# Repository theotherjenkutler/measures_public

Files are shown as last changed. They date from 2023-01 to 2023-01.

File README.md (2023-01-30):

# Measures
## An ecosystem for detection of physiological indicators of empathy.
<p>MEASURES is a flexible web based, AI driven eco-system which lends itself to live performance, 
<br>installation in a gallery museum, festival or alone in one's bedroom while being simple enough 
<br>for anyone with WIFI and a smartphone to use.
<br>It fuses technology and emotion where technology is often sterile and intellectual and offers 
<br>tools for self reflection while creating a method of studying the phenomenon of empathy as a whole. 
<br>Ultimately, MEASURES offers a new way to feel connected and to experience one another across borders, 
<br>cultures, socioeconomic classes and other zones of isolation.

<p>Users wear an electronic wristband which provides audio cues and measures the participant's electrodermal
<br>activity. The data is transferred over WIFI to a server which processes the data and generates a unique sound work.
<br>Each sound work produced by a participant is subsequently analyzed for point of “excitation” using Opensmile 
<br>feature extraction trained by a custom piece specific data set. The results are used as the basis of the following 
<br>user's auditory stimuli and physiological data comparison to generate the next sound piece and so on. The sound 
<br>works are added to a public online archive. Participants can choose to disclose their identity or remain anonymous.
<br>To my knowledge, MEASURES is the first system in the artistic and scientific communities designed with the 
<br>specific purpose of quantifying and measuring empathy from auditory cues. MEASURES content originates from an 
<br>infinitely expansive pool of participant data is comprised of empathetic responses for an AI driven art work.

<p>The goals of this piece put the wealth seeking uses of AI such as advertising, facial/voice recognition, fraud 
<br>prevention and other commercial applications in the background. It focuses on AI as a tool to witness people in 
<br>the most human way possible – through experiencing a person feeling empathy.
<br>The form of MEASURES is also unique because the data collection device exists as an electronic art object and 
<br>generates an expansive bio-data driven archive of individual sound works, and is designed to be extremely 
<br>accessible as a tool for installation, real-time performance and solitary use.

<p>The hardware uses a custom EDA sensor based on the AD8608 op-amp and handmade carbon silicone sensor pads.
<br>MP3 decoding is handled by the VS1053b chip connected to the ESP32WROVER over SPI.
<br>For ADC it uses an ADS1115 IC over the I2C Bus. 
 
<p>This repo will include 
<br>- Arduino firmware code for the ESP32-WROVER,
<br>- Node-Red code with respective shell scripts, 
<br>- PureData patches for sonification, 
<br>- EAGLE CAD files of schematics and PCB layout,
<br>- TensorFlow and Pytorch code

<p>Server Requirements:
<br>- Ubuntu or similar
<br>- Icecast2 // icecast.org
<br>- FFMPEG // ffmpeg.org
<br>- PureData // puredata.info
<br>- Node-Red // nodered.org
<br>- inotifytools // https://github.com/inotify-tools/inotify-tools

<p>Device Firmware Requirements:
<br>- Arduino IDE + ESP32 Arduino
<br>- External Libraries:
<br>- Adafruit_VS1053 // https://github.com/adafruit/Adafruit_VS1053_Library
<br>- WiFi Manager // https://github.com/tzapu/WiFiManager
<br>- ADS1X15 // https://github.com/RobTillaart/ADS1X15

<p>Detailed system description:
<br>TODO

<p>Relavent links/Bibliography:
<br>TODO
<br>https://arxiv.org/pdf/2008.09743.pdf Guanghao Yin, Shouqian Sun, Dian Yu and Kejun Zhang*, Member, 
<br>IEEE in their paper A Efficient Multimodal Framework for Large Scale Emotion Recognition by Fusing Music 
<br>and Electrodermal Activity Signals. openSMILE https://audeering.github.io/opensmile/ to obtain external feature 
<br>vectors of audio cues

 <br>Measures is made possible in part by the New York State Council on the Arts with the support of the Office of 
 <br>the Governor and the New York State Legislature and Wave Farm.
<br>

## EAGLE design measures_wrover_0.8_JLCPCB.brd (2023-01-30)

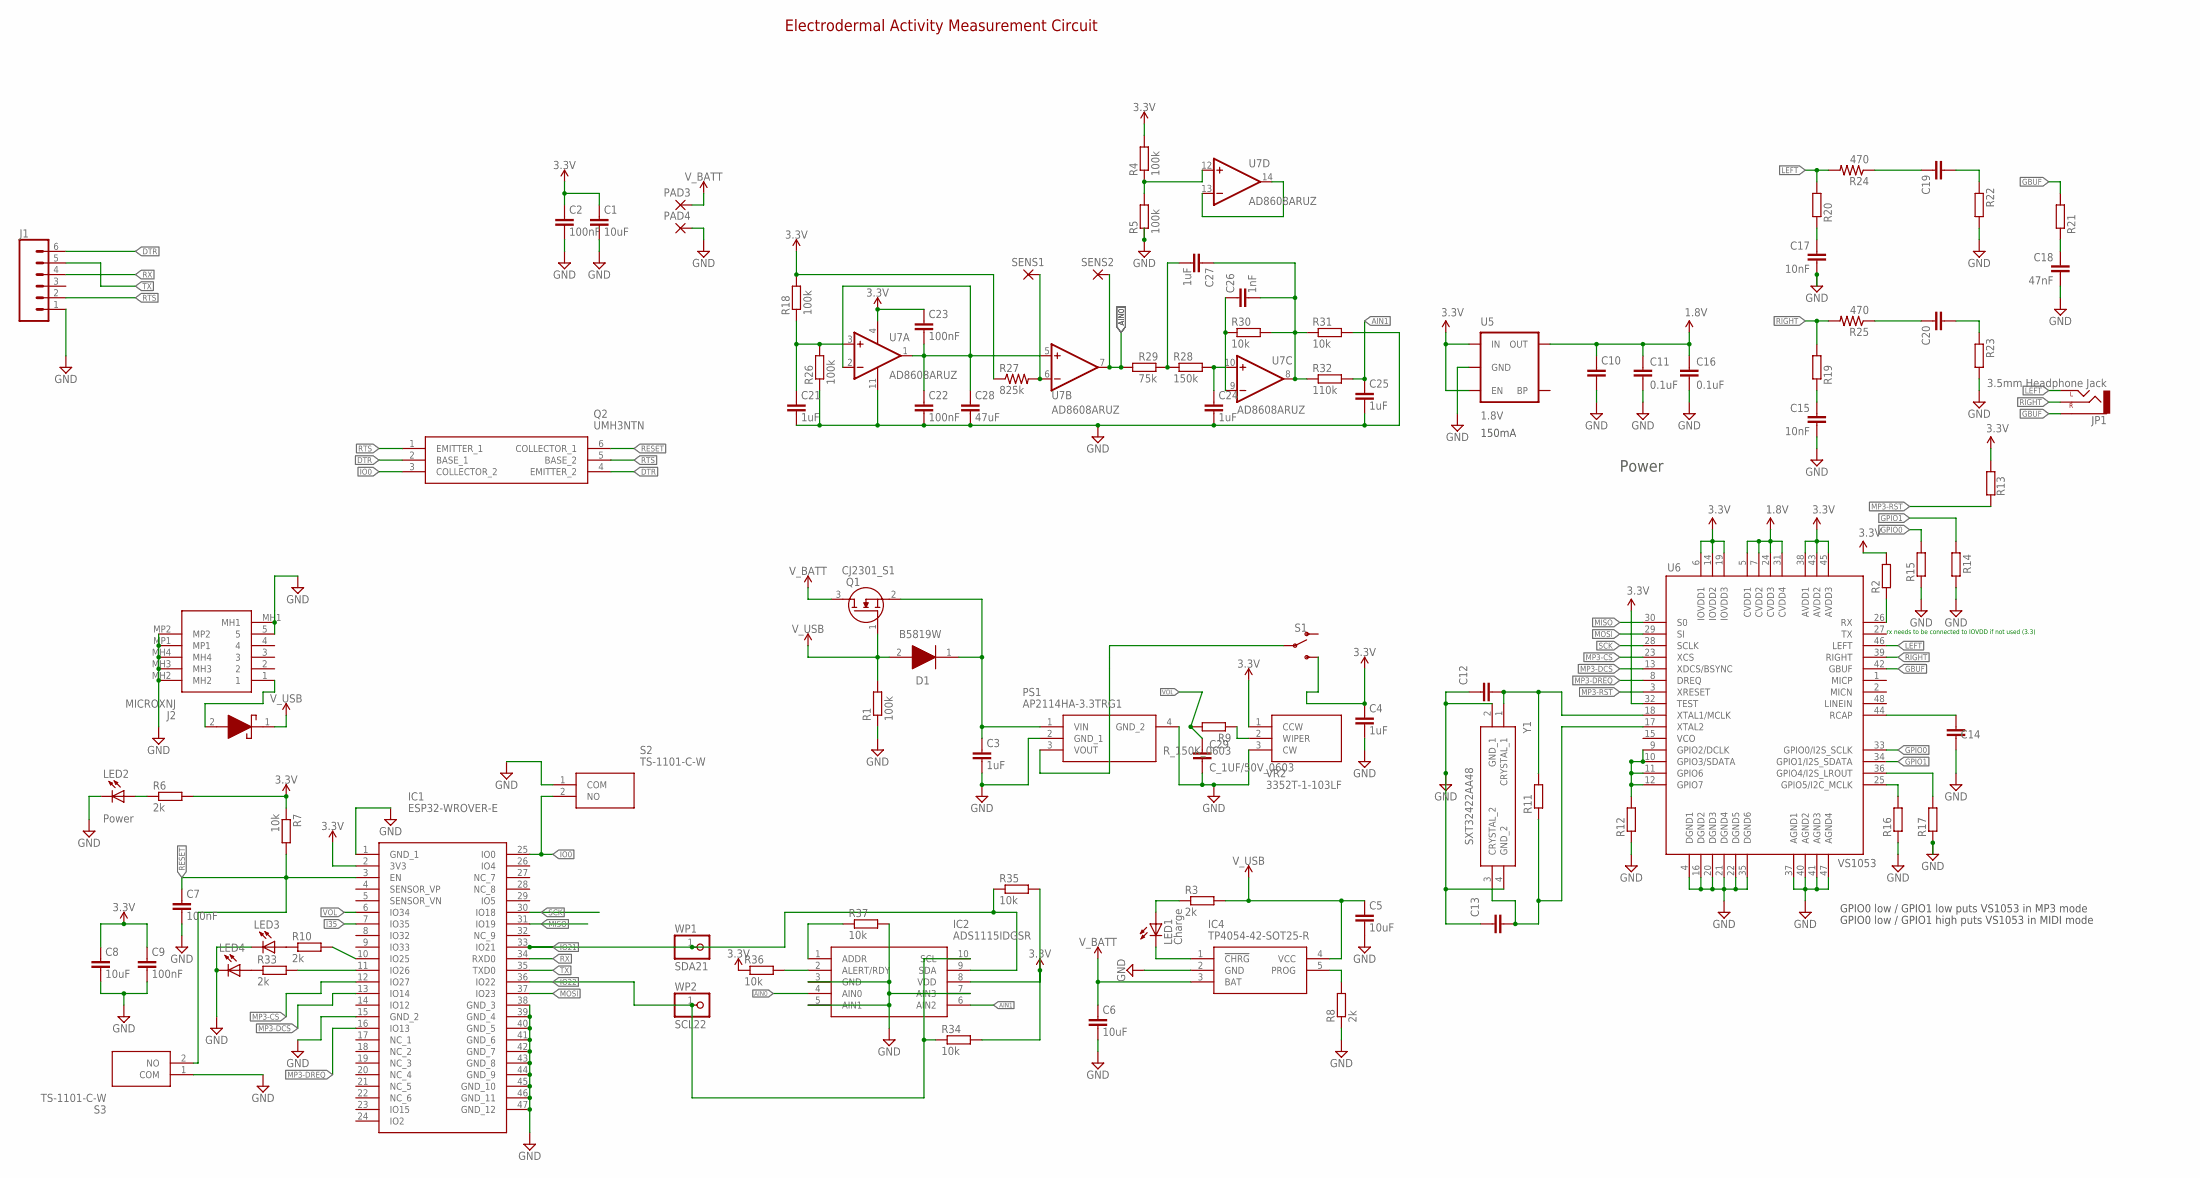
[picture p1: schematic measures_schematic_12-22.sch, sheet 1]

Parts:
C1, C5, C6, C8, C10, C19, C20: 10uF; C0603
C2, C7, C9, C22, C23: 100nF; C0603
C3, C4, C21, C25: 1uF; C0402
C11, C16: 0.1uF; 0603-CAP
C12, C13: 22pF; C0603
C14: 1.0uF; C0402
C15, C17: 10nF; 0603-CAP
C18: 47nF; 0603-CAP
C24, C27: 1uF; C0603
C26: 1nF; C0603
C28: 47uF; C1206
C29: C_1UF/50V_0603; C0603
D1: B5819W; SOD3716X125N
D5: BAT760-7; SOD2513X120N
IC1: ESP32-WROVER-E; ESP32WROVERE
IC2: ADS1115IDGSR; SOP50P490X110-10N
IC4: TP4054-42-SOT25-R; SOT95P280X100-5N
J1: CONN_06NO_SILK_FEMALE_PTH; 1X06_NO_SILK
J2: MICROXNJ
JP1: 3.5mm Headphone Jack; AUDIO-JACK-3.5MM-SMD
LED1: Charge; CHIP-LED0603
LED2, LED3, LED4: Power; CHIP-LED0603
PAD3, PAD4: 2,54/0,8
PS1: AP2114HA-3.3TRG1; SOT230P700X180-4N
Q1: CJ2301_S1; SOT95P240X115-3N
Q2: UMH3NTN
R1, R2, R4, R5, R12, R13, R14, R15, R16, R17, R18, R26: 100k; R0603
R3, R6, R8, R10, R33: 2k; R0603
R7, R30, R31, R34, R35, R36, R37: 10k; R0603
R9: R_150K_0603; R0603
R11: 1M; R0603
R19, R20: 20; R0603
R21: 10; R0603
R22, R23: 10K; R0603
R24, R25: 470; 0603-RES
R27: 825k; R0402
R28: 150k; R0402
R29: 75k; R0402
R32: 110k; R0603
S1: SWITCH-SPDT-PTH-11.6X4.0MM; SWITCH_SPDT_PTH_11.6X4.0MM
S2, S3: TS-1101-C-W; TS1101CW
SENS1, SENS2: 2,54/0,8
U5: 1.8V; SC70
U6: VS1053; LQFP-48
U7: AD8608ARUZ; TSSOP14
VR2: 3352T-1-103LF; 3352T1103LF
WP1: SDA21; WPAD-1-0805
WP2: SCL22; WPAD-1-0805
Y1: SXT32422AA48

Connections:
1.8V: C10.1, C11.1, C16.1, U5.5 (OUT), U6.5 (CVDD1), U6.7 (CVDD2), U6.24 (CVDD3), U6.31 (CVDD4)
AIN0: IC2.4 (AIN0), R29.1, SENS2.1, U7.7 (OUT)
AIN1: C25.1, IC2.6 (AIN2), R32.2
DTR: J1.6, Q2.2 (BASE_1), Q2.4 (EMITTER_2)
G1: R12.2, U6.9 (GPIO2/DCLK), U6.10 (GPIO3/SDATA), U6.11 (GPIO6), U6.12 (GPIO7)
G2: R16.2, U6.25 (GPIO5/I2C_MCLK)
GBUF: JP1.SLEEVE, R21.2, U6.42 (GBUF)
GND: C1.2, C2.2, C3.2, C4.2, C5.2, C6.2, C7.2, C8.2, C9.2, C10.2, C11.2, C12.1, C13.1, C14.1, C15.2, C16.2, C17.2, C18.2, C21.2, C22.2, C24.2, C25.2, C28.2, C29.2, IC1.1 (GND_1), IC1.15 (GND_2), IC1.38 (GND_3), IC1.39 (GND_4), IC1.40 (GND_5), IC1.41 (GND_6), IC1.42 (GND_7), IC1.43 (GND_8), IC1.44 (GND_9), IC1.45 (GND_10), IC1.46 (GND_11), IC1.47 (GND_12), IC2.3 (GND), IC2.5 (AIN1), IC2.7 (AIN3), IC4.2 (GND), J1.1, J2.5, J2.MH1, J2.MH2, J2.MH3, J2.MH4, J2.MP1, J2.MP2, LED2.C, LED3.C, LED4.C, PAD4.1, PS1.2 (GND_1), PS1.4 (GND_2), R1.1, R5.1, R8.1, R12.1, R14.1, R15.1, R16.1, R17.1, R22.2, R23.2, R26.1, R31.2, R37.2, S2.1 (COM), S3.1 (COM), U5.2 (GND), U6.4 (DGND1), U6.16 (DGND2), U6.20 (DGND3), U6.21 (DGND4), U6.22 (DGND5), U6.35 (DGND6), U6.37 (AGND1), U6.40 (AGND2), U6.41 (AGND3), U6.47 (AGND4), U7.11 (GND), VR2.3 (CW), Y1.2 (GND_1), Y1.4 (GND_2)
GPIO0: R15.2, U6.33 (GPIO0/I2S_SCLK)
GPIO1: R14.2, U6.34 (GPIO1/I2S_SDATA)
GPIO4: R17.2, U6.36 (GPIO4/I2S_LROUT)
I35: IC1.7 (IO35)
IO0: IC1.25 (IO0), Q2.3 (COLLECTOR_2), S2.2 (NO)
IO21: IC1.33 (IO21), IC2.9 (SDA), R35.1, WP1.1
IO22: IC1.36 (IO22), IC2.10 (SCL), R34.1, WP2.1
LEFT: JP1.TIP (LEFT), R20.2, R24.2, U6.46 (LEFT)
MIDI-RX: R2.1, U6.26 (RX)
MISO: IC1.31 (IO19), U6.30 (S0)
MOSI: IC1.37 (IO23), U6.29 (SI)
MP3-CS: IC1.12 (IO27), U6.23 (XCS)
MP3-DCS: IC1.13 (IO14), U6.13 (XDCS/BSYNC)
MP3-DREQ: IC1.16 (IO13), U6.8 (DREQ)
unnamed: PS1.3 (VOUT), S1.2
unnamed: C3.1, D1.1 (K), PS1.1 (VIN), Q1.2 (S)
unnamed: LED2.A, R6.1
unnamed: IC4.1 (!CHRG), LED1.C
unnamed: LED1.A, R3.1
unnamed: D5.2 (A), J2.1
unnamed: IC4.5 (PROG), R8.2
unnamed: R9.1, VR2.2 (WIPER)
unnamed: R4.1, R5.2, U7.12 (+IN)
unnamed: U7.13 (-IN), U7.14 (OUT)
unnamed: IC1.10 (IO25), R10.2
unnamed: IC1.11 (IO26), R33.2
unnamed: C12.2, R11.2, U6.18 (XTAL1/MCLK), Y1.1 (CRYSTAL_1)
unnamed: C13.2, R11.1, U6.17 (XTAL2), Y1.3 (CRYSTAL_2)
unnamed: C18.1, R21.1
unnamed: C17.1, R20.1
unnamed: C15.1, R19.1
unnamed: C20.1, R25.1
unnamed: C19.1, R24.1
unnamed: C21.1, R18.1, R26.2, U7.3 (+IN)
unnamed: C22.1, C23.2, C28.1, U7.1 (OUT), U7.2 (-IN), U7.5 (+IN)
unnamed: R27.2, SENS1.1, U7.6 (-IN)
unnamed: C24.1, R28.2, U7.10 (+IN)
unnamed: C26.2, C27.1, R30.2, R31.1, R32.1, U7.8 (OUT)
unnamed: C26.1, R30.1, U7.9 (-IN)
unnamed: C27.2, R28.1, R29.2
unnamed: LED3.A, R10.1
unnamed: LED4.A, R33.1
unnamed: IC2.2 (ALERT/RDY), R36.2
unnamed: IC2.1 (ADDR), R37.1
RCAP: C14.2, U6.44 (RCAP)
RESET: C7.1, IC1.3 (EN), Q2.6 (COLLECTOR_1), R7.2, S3.2 (NO)
RIGHT: JP1.RING (RIGHT), R19.2, R25.2, U6.39 (RIGHT)
RTS: J1.2, Q2.1 (EMITTER_1), Q2.5 (BASE_2)
RX: IC1.34 (RXD0), J1.4
SCK: IC1.30 (IO18), U6.28 (SCLK)
SPKR-L: C19.2, R22.1
SPKR-R: C20.2, R23.1
TX: IC1.35 (TXD0), J1.5
VOL: C29.1, IC1.6 (IO34), R9.2
V_BATT: C6.1, IC4.3 (BAT), PAD3.1, Q1.3 (D)
V_USB: C5.1, D1.2 (A), D5.1 (K), IC4.4 (VCC), Q1.1 (G), R1.2, R3.2

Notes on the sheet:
Power
150mA
GPIO0 low / GPIO1 high puts VS1053 in MIDI mode
GPIO0 low / GPIO1 low puts VS1053 in MP3 mode
Electrodermal Activity Measurement Circuit
rx needs to be connected to IOVDD if not used (3.3)

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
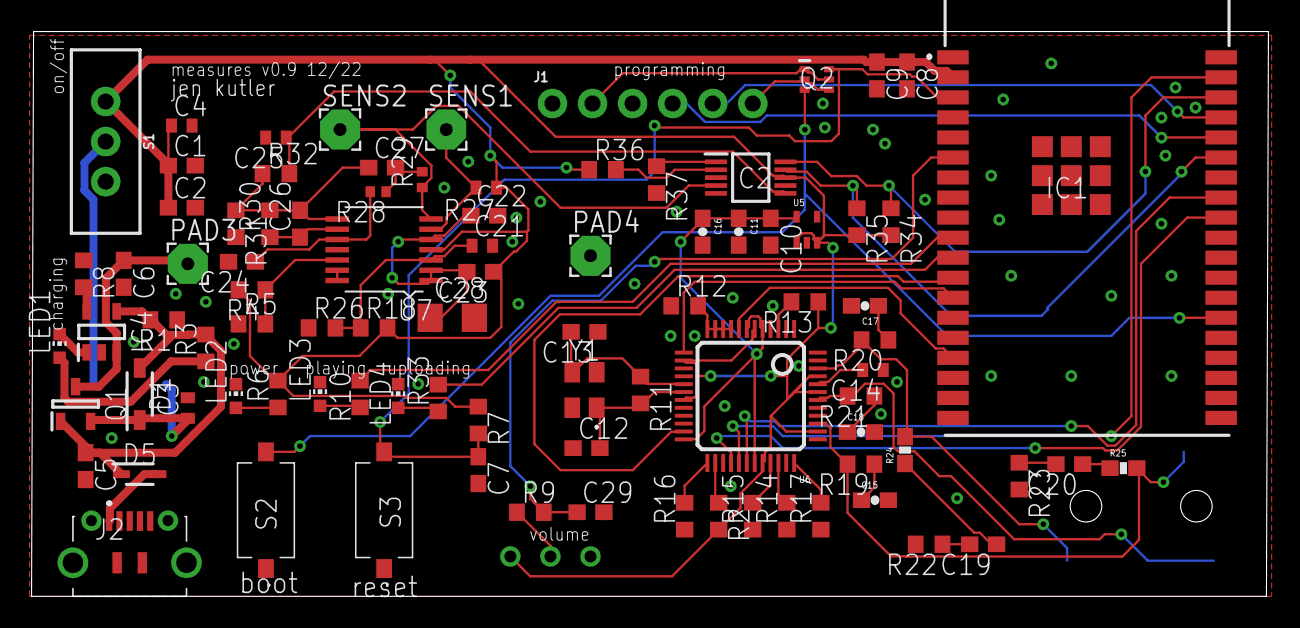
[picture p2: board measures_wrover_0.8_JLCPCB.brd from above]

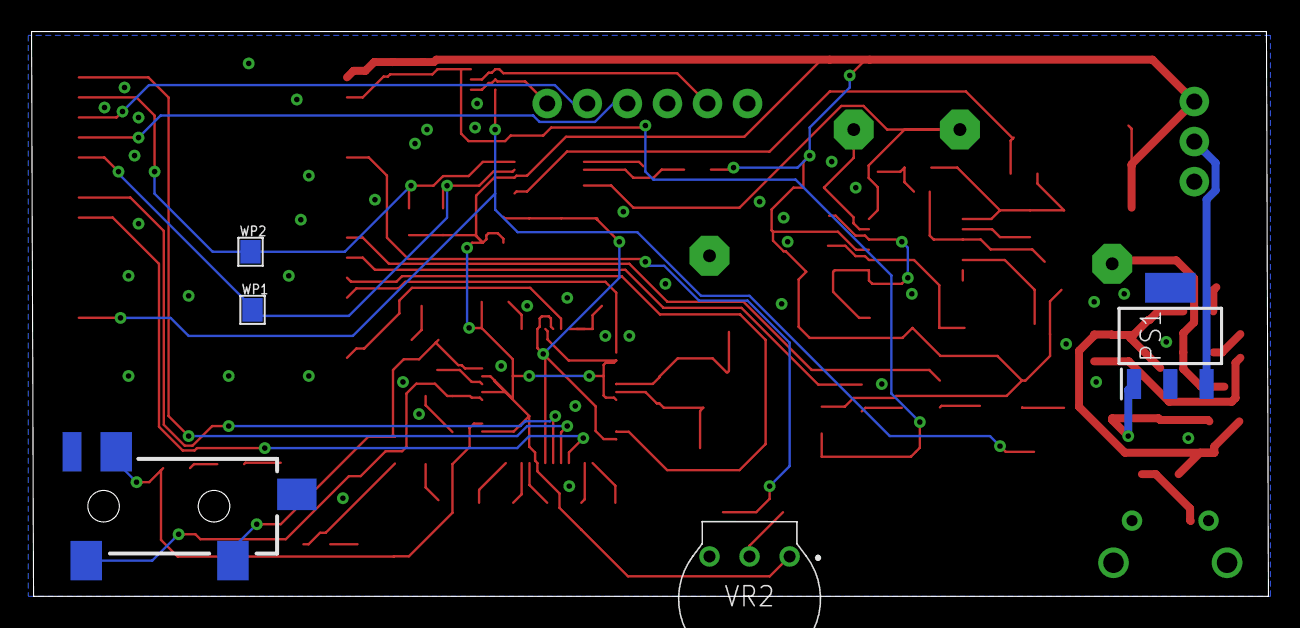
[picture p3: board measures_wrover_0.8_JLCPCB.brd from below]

Board: 2 copper layers, 78.4 x 35.8 mm, 95 parts (5 on the bottom side), 65 nets.

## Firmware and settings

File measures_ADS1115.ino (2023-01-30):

//***************************************//
// Measures (ESP32WROVER-16MB)           //
//                                       //
// jenkutler.com                         //
// **************************************//

//To do: 
//fix issue caused by i2c blocking core 1 for ads1115 readings
//Create a 4-character code for node-red to get rid of spam connections and crawlers
//compare readings from filtered and unfiltered eda pins and pick one


#include <SPI.h>
#include <Adafruit_VS1053.h>
#include <WiFi.h>
#include <Arduino.h>
#include <WiFiManager.h>           //https://github.com/tzapu/WiFiManager
#include "FS.h"
#include "SPIFFS.h"
#include "ADS1X15.h"               //https://github.com/RobTillaart/ADS1X15

ADS1115 ADS(0x48); 

#define FORMAT_SPIFFS_IF_FAILED true
const char filename[] = "/i.txt";
File file;

unsigned long ohShit; //in case node-red doesn't respond fast enough with stream

char macIdentifierNodeRed[17];

char uniquePath[20];
const char *host = "146.190.221.89";
String path = "/000000000000.mp3";
int httpPort = 8000;

WiFiClient transferClient;
const int transferPort = 49153;

WiFiClient initClient;
const int initPort = 49152;

//int edasamplecounter = 0;
size_t edaBuffSize = 128;
int16_t edaUnfilt[128] = {0}; 

//#define EDAUNFILTPIN 33
#define PLAYING_INDICATOR 25
#define END_INDICATOR 26
#define VS1053_RESET   -1     // VS1053 reset pin (not used!)
#define VS1053_CS      27     // VS1053 chip select pin (output)
#define VS1053_DCS     14     // VS1053 Data/command select pin (output)
#define VS1053_DREQ    13     // VS1053 Data request, ideally an Interrupt pin

#define VOLUME_KNOB    34

int lastvol = 30;

Adafruit_VS1053 musicPlayer =  Adafruit_VS1053(VS1053_RESET, VS1053_CS, VS1053_DCS, VS1053_DREQ);

WiFiClient audioClient;

void setup() {
  WiFi.mode(WIFI_STA); 
  
  Serial.begin(115200);

  // Wait for VS1053 to initialize
  delay(3000);
   if (! musicPlayer.begin()) { // initialise the music player
     Serial.println(F("VS1053 Failure"));
     while (1);
  }
  
  musicPlayer.setVolume(lastvol, lastvol);
  pinMode(VOLUME_KNOB, INPUT_PULLUP);
  pinMode(PLAYING_INDICATOR, OUTPUT);
  pinMode(END_INDICATOR, OUTPUT);
  digitalWrite(PLAYING_INDICATOR, LOW);
  digitalWrite(END_INDICATOR, LOW);

  WiFiManager wm;
  bool res;
  res = wm.autoConnect("Measures","measures");
  if(!res){
    Serial.println(F("WiFi Failure"));
    //ESP.restart();
  }else{
    Serial.println(F("WiFi Connected"));
  }
  while(WiFi.status() != WL_CONNECTED){
    delay(100);
  }

  if(!SPIFFS.begin(FORMAT_SPIFFS_IF_FAILED)){
    Serial.println(F("SPIFFS Mount Failed"));
    return;
  }

  if (!SPIFFS.remove(filename)){
    Serial.println(F("File not deleted"));
  };

  delay(10);

  file = SPIFFS.open(filename, FILE_APPEND);
  if(!file){
    Serial.println(F("SPIFFS can't open file"));
  }
  if(!ADS.begin()){
    Serial.println(F("ADS Failed"));
    while(1);
  }

  getMacIdentifier(); //gets mac address for node-red

  //send mac address to node-red
  if(!initClient.connect(host, initPort)){
    Serial.println(F("Init TCP failed"));
    while(true){
      ;
    }
  }else{
    Serial.println(F("Init TCP success"));
    initClient.println(macIdentifierNodeRed);
    delay(10);
    initClient.stop();
  }
  
  delay(200);

  ADS.requestADC(0);
  
  if (!audioClient.connect(host, httpPort)) {
    Serial.println(F("Icecast failed"));
    return;
  }
  
  // This will send the stream request to the server
  audioClient.print(String("GET ") + path + " HTTP/1.1\r\n" +
               "Host: " + host + "\r\n" + 
               "Connection: close\r\n\r\n");

  //Serial.println("endofsetup");printMem();
}

uint8_t mp3buff[32];   // vs1053 audio buffer
size_t bytes_read;
int readCounter = 0;
bool needNewSample = false; //because it is first called in setup

void loop() {

  if(audioClient.connected()){ //still in data acquisition section of program
    digitalWrite(PLAYING_INDICATOR, HIGH);
    
    //in order of priority
    if(musicPlayer.readyForData() && audioClient.available()) {
      uint8_t bytesread = audioClient.read(mp3buff, 32);
      musicPlayer.playData(mp3buff, bytesread);
    }

    if((!musicPlayer.readyForData()) && (readCounter == edaBuffSize)){ 

      for (int i=0; i<edaBuffSize; i++){
        file.println(edaUnfilt[i]);
      }
      //Serial.print("File Size: ");
      //Serial.println(file.size());
      readCounter = 0;
    } 
    
    if(!musicPlayer.readyForData() && !ADS.isBusy()){
      //read sample from i2c ads1115
      if(needNewSample == false){
        edaUnfilt[readCounter] = ADS.getValue(); 
        //Serial.print("Value: "); Serial.println(edaUnfilt[readCounter]);
        //Serial.print("Read Counter: "); Serial.println(readCounter);
        readCounter++;
        needNewSample = true;
      }
    } 
    if (!musicPlayer.readyForData() && !ADS.isBusy()){
      if(needNewSample == true){
        ADS.requestADC(0); // this might need to go in a different function 
        needNewSample = false;
      }
    }
    
    if ((!musicPlayer.readyForData()) && (readCounter < edaBuffSize/4)){ // /4 is to make this less frequent
      int vol = analogRead(VOLUME_KNOB);
      vol /= 25;
      if (abs(vol - lastvol) > 3) {
        lastvol = vol;
        musicPlayer.setVolume(lastvol, lastvol);
      }
    }    
  }

  if(!audioClient.connected()){ //move to upload section of program
  digitalWrite(PLAYING_INDICATOR, LOW);
  digitalWrite(END_INDICATOR, HIGH);
  //Serial.println("AUDIOCLIENT NO LONGER CONNECTED"); 
  file.close();
  audioClient.stop();
  uploadData();
  endOfProgram(); 
  }
}

void getMacIdentifier(){
  byte mac[6];
  WiFi.macAddress(mac);
  for (int i = 5; i>=0; i--){
    if(mac[i] < 16){
      Serial.print(F("getMacIdentifier() has failed"));
    }
  }
  sprintf(macIdentifierNodeRed, "%02X%02X%02X%02X%02X%02X", mac[5], mac[4], mac[3], mac[2], mac[1], mac[0]);
  sprintf(uniquePath, "/%02X%02X%02X%02X%02X%02X.mp3", mac[5], mac[4], mac[3], mac[2], mac[1], mac[0]);
  path = uniquePath;
  Serial.println(uniquePath);
}

void uploadData(){
  ohShit = millis();
  if(ohShit < 10000){
    ESP.restart();
  }
  
  delay(5);
  //Serial.println("UPLOAD DATA CALLED");
  if(!transferClient.connect(host, transferPort)){
    Serial.println(F("transferClient connection failed"));
    while(true){
      ;
    }
  } else {
    //Serial.println(F("DATA TRANSFER INITIATED"));

    char fileBuffer[32];
    
    file = SPIFFS.open(filename);

    if(!file){
      Serial.print("Could not open file");
      while(true){
        ;
      }
    }

    size_t fileSize = (file.size());
    size_t sizeToTransfer = fileSize;
    
    //Serial.println(file.size());
    
    while(file.available()){
      while (sizeToTransfer > 0){
        char edaBuffer[edaBuffSize * 2] = {0};
        file.readBytes(edaBuffer, edaBuffSize);
        transferClient.write(edaBuffer, edaBuffSize);
        sizeToTransfer -=  edaBuffSize;
        //Serial.println(sizeToTransfer);
        if(sizeToTransfer <= edaBuffSize){
          file.close();
        }
      }
    }
         
    transferClient.stop();
    //Serial.println(F("DATA TRANSFER COMPLETE"));
    digitalWrite(END_INDICATOR, LOW);
   }
}


void endOfProgram(){
  while (1){
    digitalWrite(END_INDICATOR, HIGH);
    delay(100);
    musicPlayer.sineTest(0x44, 1000);    // Annoying tone prompting user to turn off device
    digitalWrite(END_INDICATOR, LOW);
    delay(100);
  }
}

/*
void printMem() {
  Serial.printf("heap_caps_get_free_size(MALLOC_CAP_SPIRAM)            : %7d\n", heap_caps_get_free_size(MALLOC_CAP_SPIRAM) );
  Serial.printf("heap_caps_get_free_size(MALLOC_CAP_INTERNAL)          : %7d\n", heap_caps_get_free_size(MALLOC_CAP_INTERNAL) );
  Serial.printf("heap_caps_get_free_size(MALLOC_CAP_DEFAULT)           : %7d\n", heap_caps_get_free_size(MALLOC_CAP_DEFAULT) );
  log_d("Free heap: %d", ESP.getFreeHeap());
  Serial.println();
}
*/

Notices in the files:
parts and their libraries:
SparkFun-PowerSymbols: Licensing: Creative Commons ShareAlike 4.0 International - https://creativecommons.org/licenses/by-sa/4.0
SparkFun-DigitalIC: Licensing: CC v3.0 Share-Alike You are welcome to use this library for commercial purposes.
